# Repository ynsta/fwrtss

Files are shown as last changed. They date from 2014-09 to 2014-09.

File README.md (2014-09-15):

fwrtss
======

[FWRTSS](https://www.ynsta.org/fwrtss/doc/html/fwrtss.html) is an open source hardware and software project of a temperature controlled soldering station designed to be used with Weller RT soldering tips.

The majority of the software used to build and debug this project are also open source:

 - KiCad (5126) for PCB design with the [amazing new interactive router from CERN team](http://www.ohwr.org/projects/cern-kicad/wiki/WorkPackages).

 - ARM cross GCC (4.8.3) & binutils,

 - GDB cross, stlink,

 - dfu-util,

 - python, pyside, pyqtgraph,

 - scons, make

 - asciidoc,

 - emacs,

 - ...

The main goal of this project was to teach myself some new stuffs as it is my first real project with a stm32 MCU and also my first surface mount PCB project with 0.5mm pitch components.
Disclaimer

# Warning
 
**A SOLDERING STATION IS A DANGEROUS TOOL**

FWRTSS open source software and hardware are provided "as is" and any express or implied warranties, including, but not limited to, the implied warranties of merchantability and fitness for a particular purpose are disclaimed. in no event shall Stany MARCEL be liable for any direct, indirect, incidental, special, exemplary, or consequential damages (including, but not limited to, procurement of substitute goods or services; loss of use, data, or profits; or business interruption) however caused and on any theory of liability, whether in contract, strict liability, or tort (including negligence or otherwise) arising in any way out of the use of this tool (in whole or in part), even if advised of the possibility of such damage.

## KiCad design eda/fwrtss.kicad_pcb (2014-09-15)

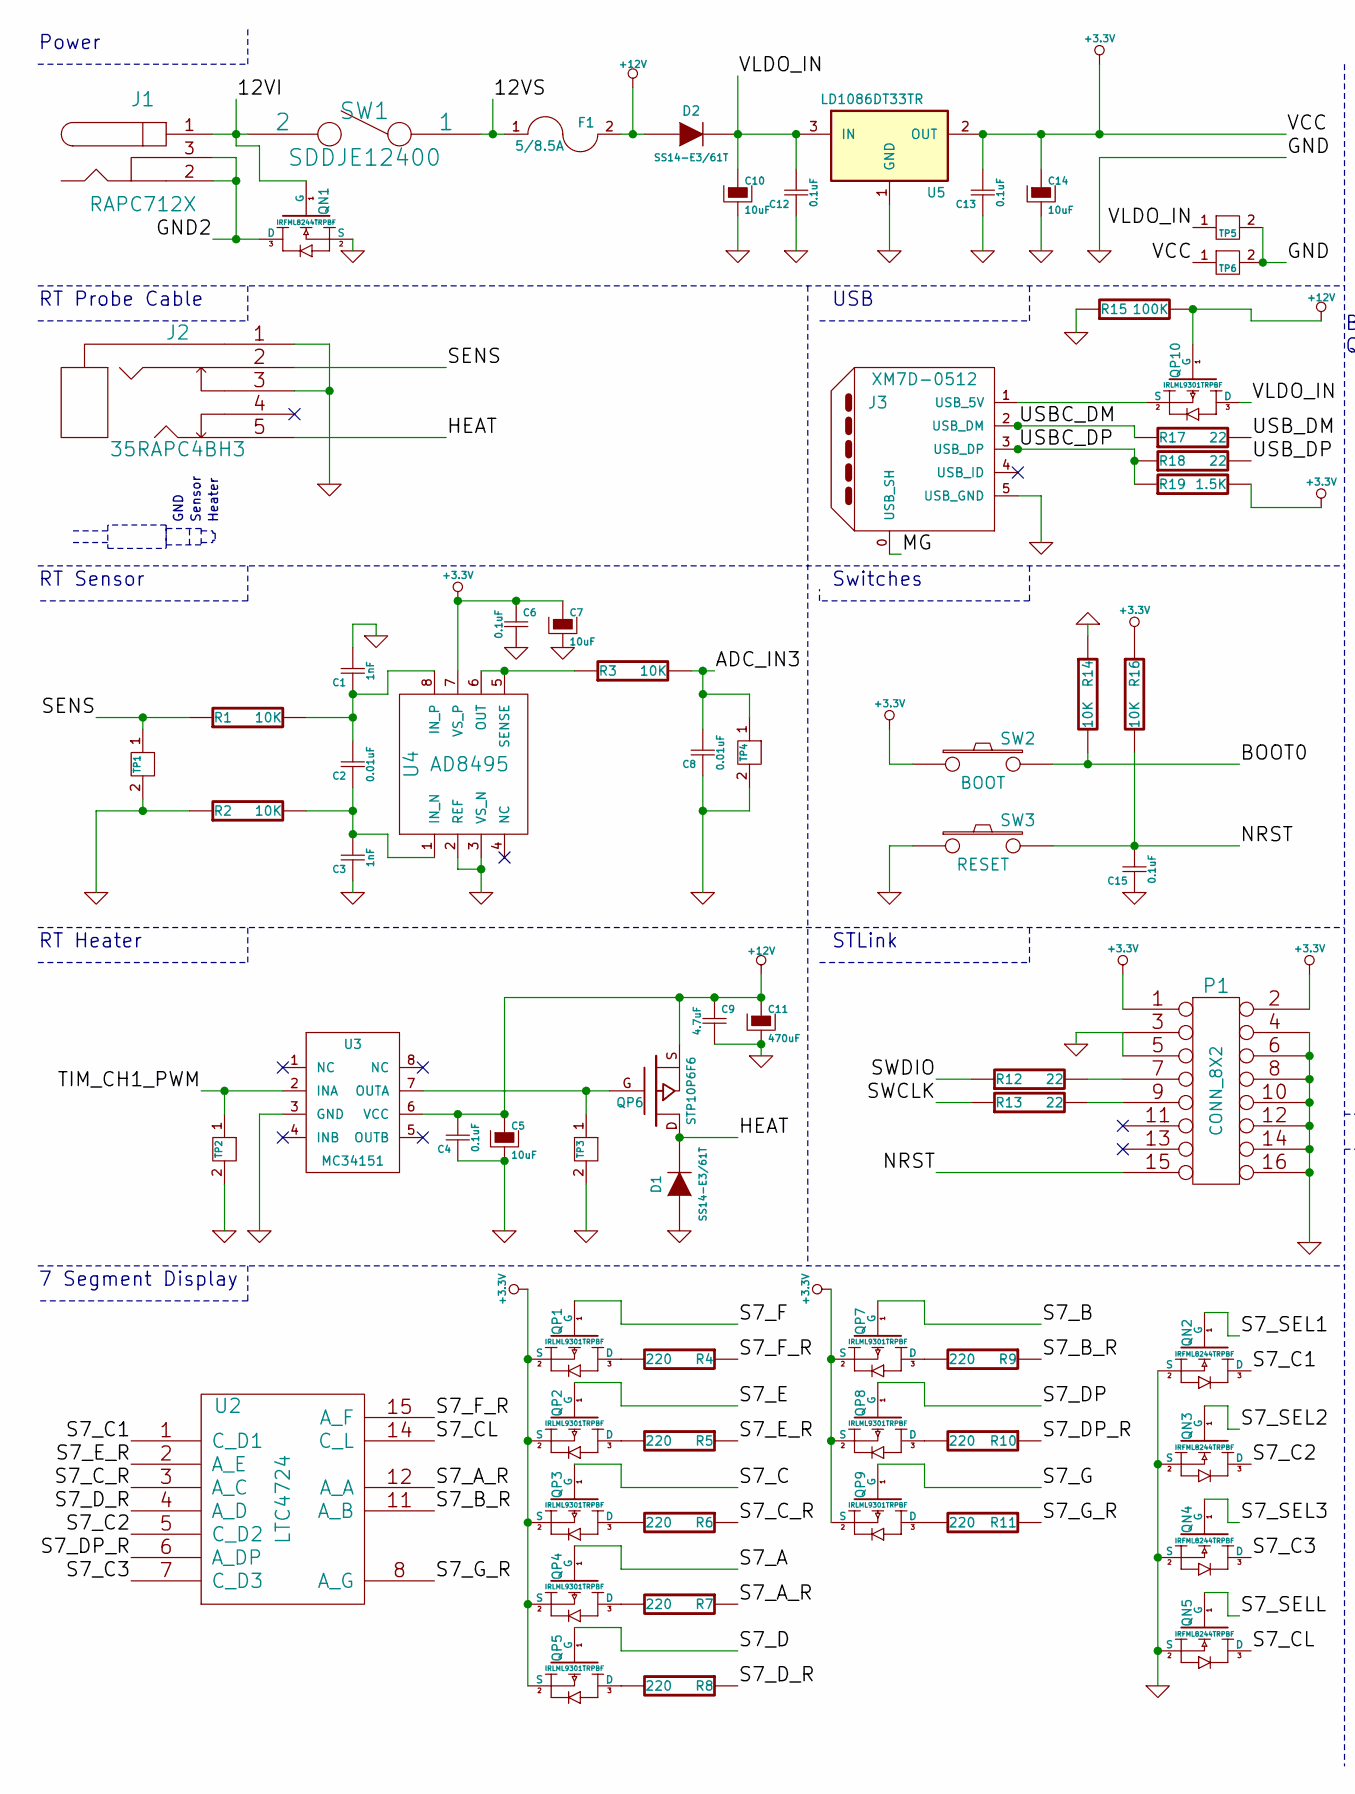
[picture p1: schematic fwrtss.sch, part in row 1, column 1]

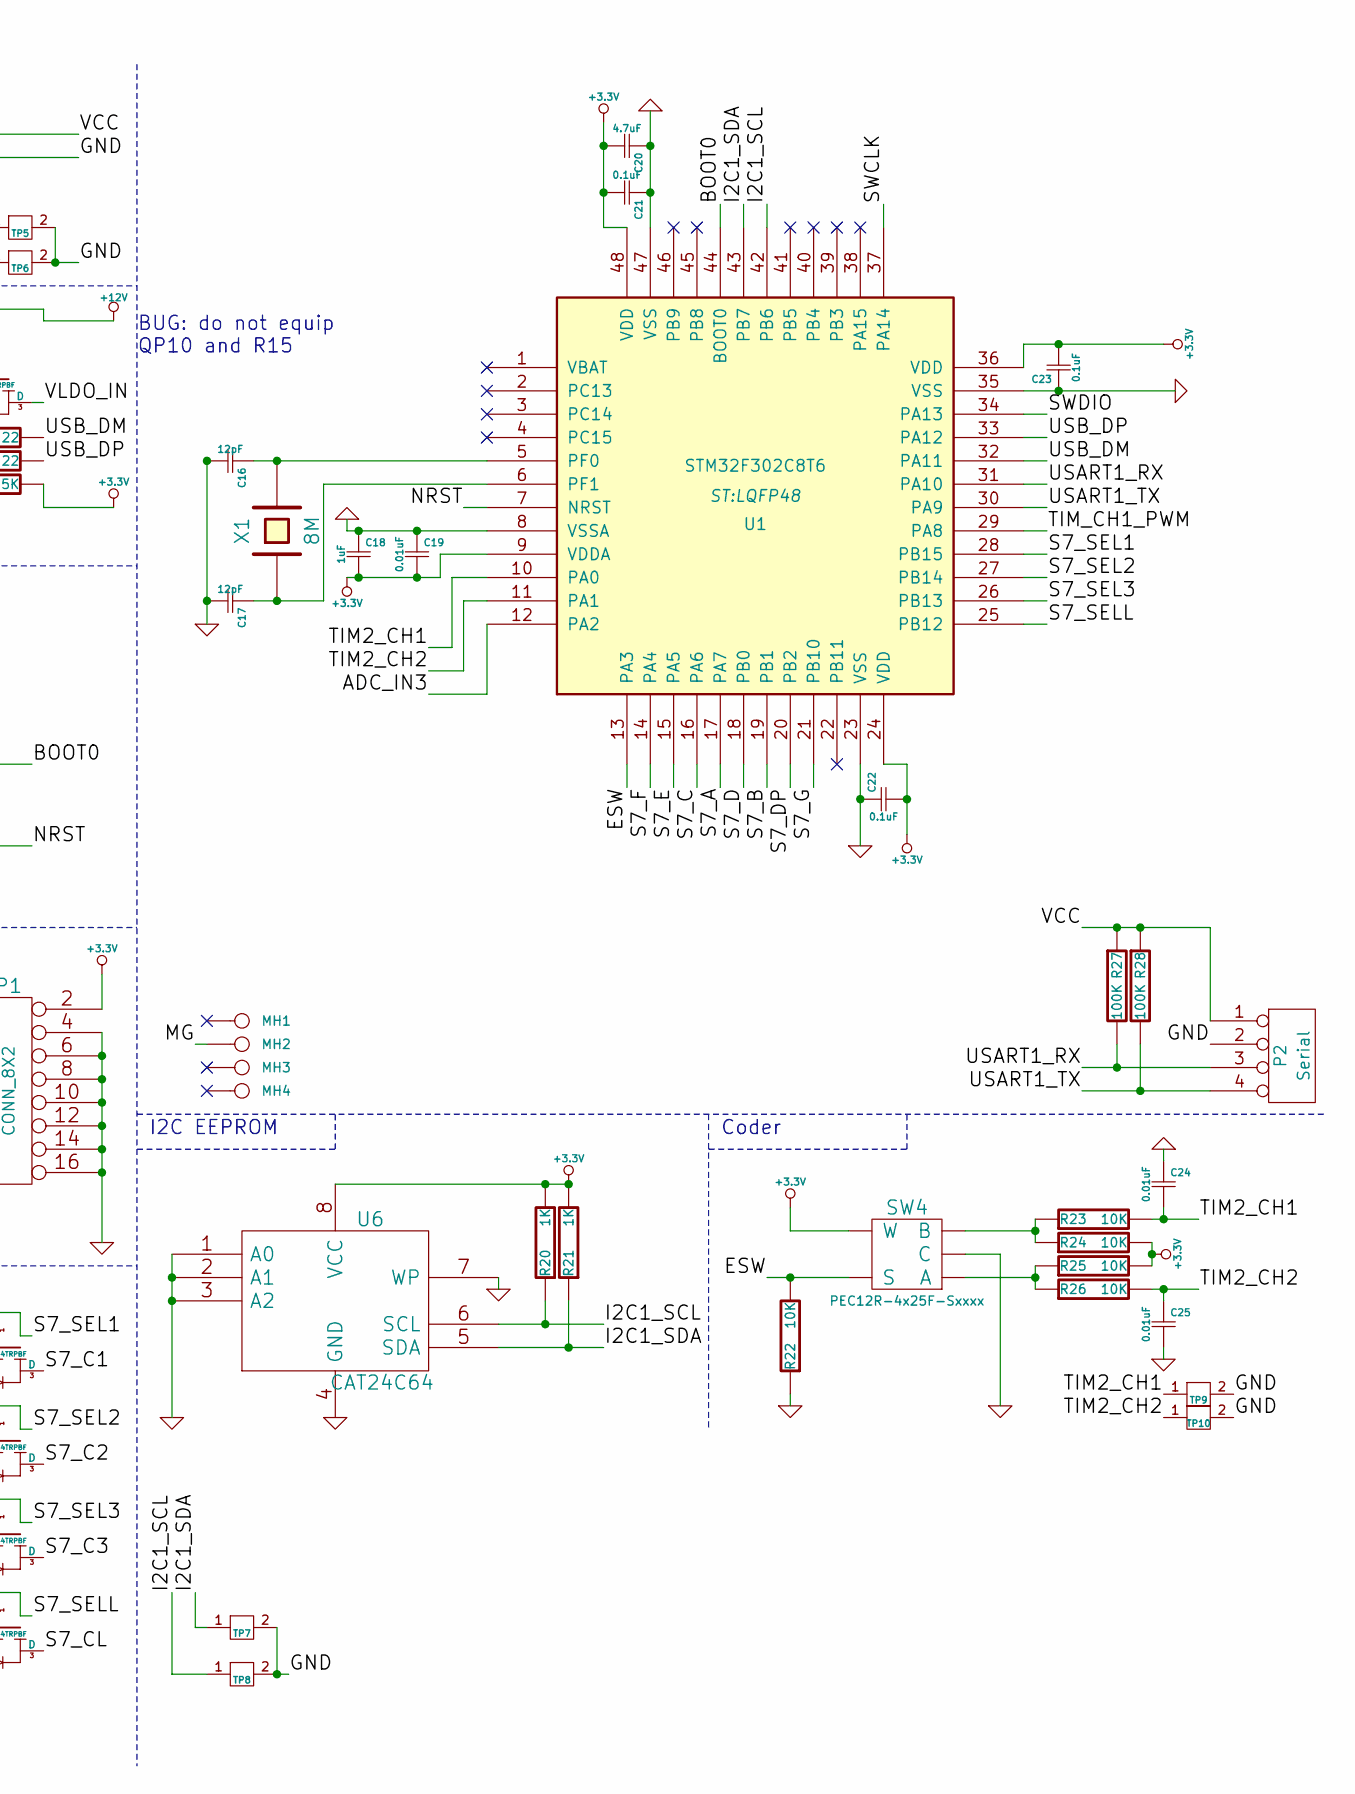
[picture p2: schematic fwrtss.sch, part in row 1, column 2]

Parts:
C1, C3: 1nF; 0805; mouser 81-GCM216R71H102KA7D
C2, C8, C19, C24, C25: 0.01uF; 0805; mouser 81-GRM40Y103Z50D
C4, C6, C12, C13, C15, C21, C22, C23: 0.1uF; 0805; mouser 81-GRM21R71C104MA01J
C5, C7, C10, C14: 10uF; Capacitor5x11RM2.5; mouser 667-EEU-EB1J100SH
C9, C20: 4.7uF; 0805; mouser 81-GRM21BR61E475KA12
C11: 470uF; Capacitor10x21RM5; mouser 647-UPW1E471MPD
C16, C17: 12pF; 0603; mouser 81-GQM1885C1H120JB01
C18: 1uF; 0805; mouser 81-GRM40X105K16L
D1, D2: SS14-E3/61T; DO214AC; mouser 625-SS14-E3
F1: 5/8.5A; Fuse_TE5_Littlefuse-395Series; mouser 650-RGEF500
J1: RAPC712X; RAPC722X; mouser 502-RAPC712X
J2: 35RAPC4BH3; mouser 502-35RAPC4BH3
J3: XM7D-0512; mouser 653-XM7D-0512
MH1, MH2, MH3, MH4: CONN_1; 1pin
P1: CONN_8X2; Pin_Header_Straight_2x08; mouser 649-67996-416HLF
P2: Serial; Pin_Header_Straight_1x04
QN1, QN2, QN3, QN4, QN5: IRFML8244TRPBF; sot23; mouser 942-IRFML8244TRPBF
QP1, QP2, QP3, QP4, QP5, QP7, QP8, QP9, QP10: IRLML9301TRPBF; sot23; mouser 942-IRLML9301TRPBF
QP6: STP10P6F6; TO-220_FET-GDS_Horizontal_LargePads; mouser 511-STP10P6F6
R1, R2, R3, R14, R16, R22, R23, R24, R25, R26: 10K; 0805; mouser 667-ERJ-6ENF1002V
R4, R5, R6, R7, R8, R9, R10, R11: 220; 0805; mouser 667-ERJ-6GEYJ221V
R12, R13, R17, R18: 22; 0805; mouser 667-ERJ-6GEYJ220V
R15, R27, R28: 100K; 0805; mouser 667-ERJ-6GEYJ104V
R19: 1.5K; 0805; mouser 667-ERJ-6GEYJ152V
R20, R21: 1K; 0805; mouser 667-ERJ-6GEYJ102V
SW1: SDDJE12400; mouser 688-SDDJE12400
SW2: BOOT; EVQ2; mouser 667-EVQ-21305R
SW3: RESET; EVQ2; mouser 667-EVQ-21305R
SW4: PEC12R-4x25F-Sxxxx; mouser 652-PEC12R-4225F-S24
TP1, TP2, TP3, TP4, TP5, TP6, TP7, TP8, TP9, TP10: TP2
U1: STM32F302C8T6; LQFP48; mouser 511-STM32F302C8T6
U2: LTC4724; LTC-4724; mouser 859-LTC-4724JR
U3: MC34151; SOIC-8_N; mouser 863-MC34151DR2G
U4: AD8495; MSOP-8; mouser 584-AD8495ARMZ
U5: LD1086DT33TR; DPAK2; mouser 511-LD1086DT33-TR
U6: CAT24C64; SOIC-8_N; mouser 698-CAT24C64WI-G
X1: 8M; X-TH-8.8-dia3.2; mouser 815-AB308-8.000

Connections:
+3.3V: C6.1, C7.1, C13.2, C14.1, C18.2, C19.2, C20.2, C21.2, C22.2, C23.2, P1.1, P1.2, P2.1, QP1.2 (S), QP2.2 (S), QP3.2 (S), QP4.2 (S), QP5.2 (S), QP7.2 (S), QP8.2 (S), QP9.2 (S), R16.1, R19.2, R20.2, R21.2, R24.2, R25.2, R27.1, R28.1, SW2.1, SW4.2 (W), TP6.1, U1.9 (VDDA), U1.24 (VDD), U1.36 (VDD), U1.48 (VDD), U4.7 (VS_P), U5.2 (OUT), U6.8 (VCC)
+12V: C4.2, C5.1, C9.1, C11.1, D2.1 (A), F1.2, QP6.S, QP10.1 (G), R15.2, U3.6 (VCC)
/12VI: J1.1, QN1.1 (G), SW1.2
/12VS: F1.1, SW1.1
/ADC_IN3: C8.2, R3.2, TP4.1, U1.12 (PA2)
/BOOT0: R14.2, SW2.2, U1.44 (BOOT0)
/ESW: R22.2, SW4.1 (S), U1.13 (PA3)
/GND2: J1.2, J1.3, QN1.3 (D)
/HEAT: D1.2 (K), J2.5, QP6.D
/I2C1_SCL: R20.1, TP8.1, U1.42 (PB6), U6.6 (SCL)
/I2C1_SDA: R21.1, TP7.1, U1.43 (PB7), U6.5 (SDA)
/MG: J3.0 (USB_SH), MH2.1
/NRST: C15.2, P1.15, R16.2, SW3.2, U1.7 (NRST)
/S7_A: QP4.1 (G), U1.17 (PA7)
/S7_A_R: R7.1, U2.12 (A_A)
/S7_B: QP7.1 (G), U1.19 (PB1)
/S7_B_R: R9.1, U2.11 (A_B)
/S7_C: QP3.1 (G), U1.16 (PA6)
/S7_C1: QN2.3 (D), U2.1 (C_D1)
/S7_C2: QN3.3 (D), U2.5 (C_D2)
/S7_C3: QN4.3 (D), U2.7 (C_D3)
/S7_CL: QN5.3 (D), U2.14 (C_L)
/S7_C_R: R6.1, U2.3 (A_C)
/S7_D: QP5.1 (G), U1.18 (PB0)
/S7_DP: QP8.1 (G), U1.20 (PB2)
/S7_DP_R: R10.1, U2.6 (A_DP)
/S7_D_R: R8.1, U2.4 (A_D)
/S7_E: QP2.1 (G), U1.15 (PA5)
/S7_E_R: R5.1, U2.2 (A_E)
/S7_F: QP1.1 (G), U1.14 (PA4)
/S7_F_R: R4.1, U2.15 (A_F)
/S7_G: QP9.1 (G), U1.21 (PB10)
/S7_G_R: R11.1, U2.8 (A_G)
/S7_SEL1: QN2.1 (G), U1.28 (PB15)
/S7_SEL2: QN3.1 (G), U1.27 (PB14)
/S7_SEL3: QN4.1 (G), U1.26 (PB13)
/S7_SELL: QN5.1 (G), U1.25 (PB12)
/SENS: J2.2, R1.1, TP1.1
/SWCLK: R13.1, U1.37 (PA14)
/SWDIO: R12.1, U1.34 (PA13)
/TIM2_CH1: C24.2, R23.2, TP9.1, U1.10 (PA0)
/TIM2_CH2: C25.1, R26.2, TP10.1, U1.11 (PA1)
/TIM_CH1_PWM: TP2.1, U1.29 (PA8), U3.2 (INA)
/USART1_RX: P2.3, R27.2, U1.31 (PA10)
/USART1_TX: P2.4, R28.2, U1.30 (PA9)
/USBC_DM: J3.2 (USB_DM), R17.1
/USBC_DP: J3.3 (USB_DP), R18.1, R19.1
/USB_DM: R17.2, U1.32 (PA11)
/USB_DP: R18.2, U1.33 (PA12)
/VLDO_IN: C10.1, C12.2, D2.2 (K), QP10.3 (D), TP5.1, U5.3 (IN)
GND: C1.2, C3.1, C4.1, C5.2, C6.2, C7.2, C8.1, C9.2, C10.2, C11.2, C12.1, C13.1, C14.2, C15.1, C16.2, C17.2, C18.1, C19.1, C20.1, C21.1, C22.1, C23.1, C24.1, C25.2, D1.1 (A), J2.1, J2.3, J3.5 (USB_GND), P1.3, P1.4, P1.5, P1.6, P1.8, P1.10, P1.12, P1.14, P1.16, P2.2, QN1.2 (S), QN2.2 (S), QN3.2 (S), QN4.2 (S), QN5.2 (S), R2.1, R14.1, R15.1, R22.1, SW3.1, SW4.4 (C), TP1.2, TP2.2, TP3.2, TP4.2, TP5.2, TP6.2, TP7.2, TP8.2, TP9.2, TP10.2, U1.8 (VSSA), U1.23 (VSS), U1.35 (VSS), U1.47 (VSS), U3.3 (GND), U4.2 (REF), U4.3 (VS_N), U5.1 (GND), U6.1 (A0), U6.2 (A1), U6.3 (A2), U6.4 (GND), U6.7 (WP)
unnamed: C1.1, C2.2, R1.2, U4.8 (IN_P)
unnamed: C2.1, C3.2, R2.2, U4.1 (IN_N)
unnamed: C16.1, U1.5 (PF0), X1.2
unnamed: C17.1, U1.6 (PF1), X1.1
unnamed: J3.1 (USB_5V), QP10.2 (S)
unnamed: P1.7, R12.2
unnamed: P1.9, R13.2
unnamed: QP1.3 (D), R4.2
unnamed: QP2.3 (D), R5.2
unnamed: QP3.3 (D), R6.2
unnamed: QP4.3 (D), R7.2
unnamed: QP5.3 (D), R8.2
unnamed: QP6.G, TP3.1, U3.7 (OUTA)
unnamed: QP7.3 (D), R9.2
unnamed: QP8.3 (D), R10.2
unnamed: QP9.3 (D), R11.2
unnamed: R3.1, U4.5 (SENSE), U4.6 (OUT)
unnamed: R23.1, R24.1, SW4.3 (B)
unnamed: R25.1, R26.1, SW4.5 (A)

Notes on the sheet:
Heater
Sensor
GND
7 Segment Display
RT Heater
RT Sensor
RT Probe Cable
Power
STLink
Coder
Switches
USB
I2C EEPROM
BUG: do not equip QP10 and R15

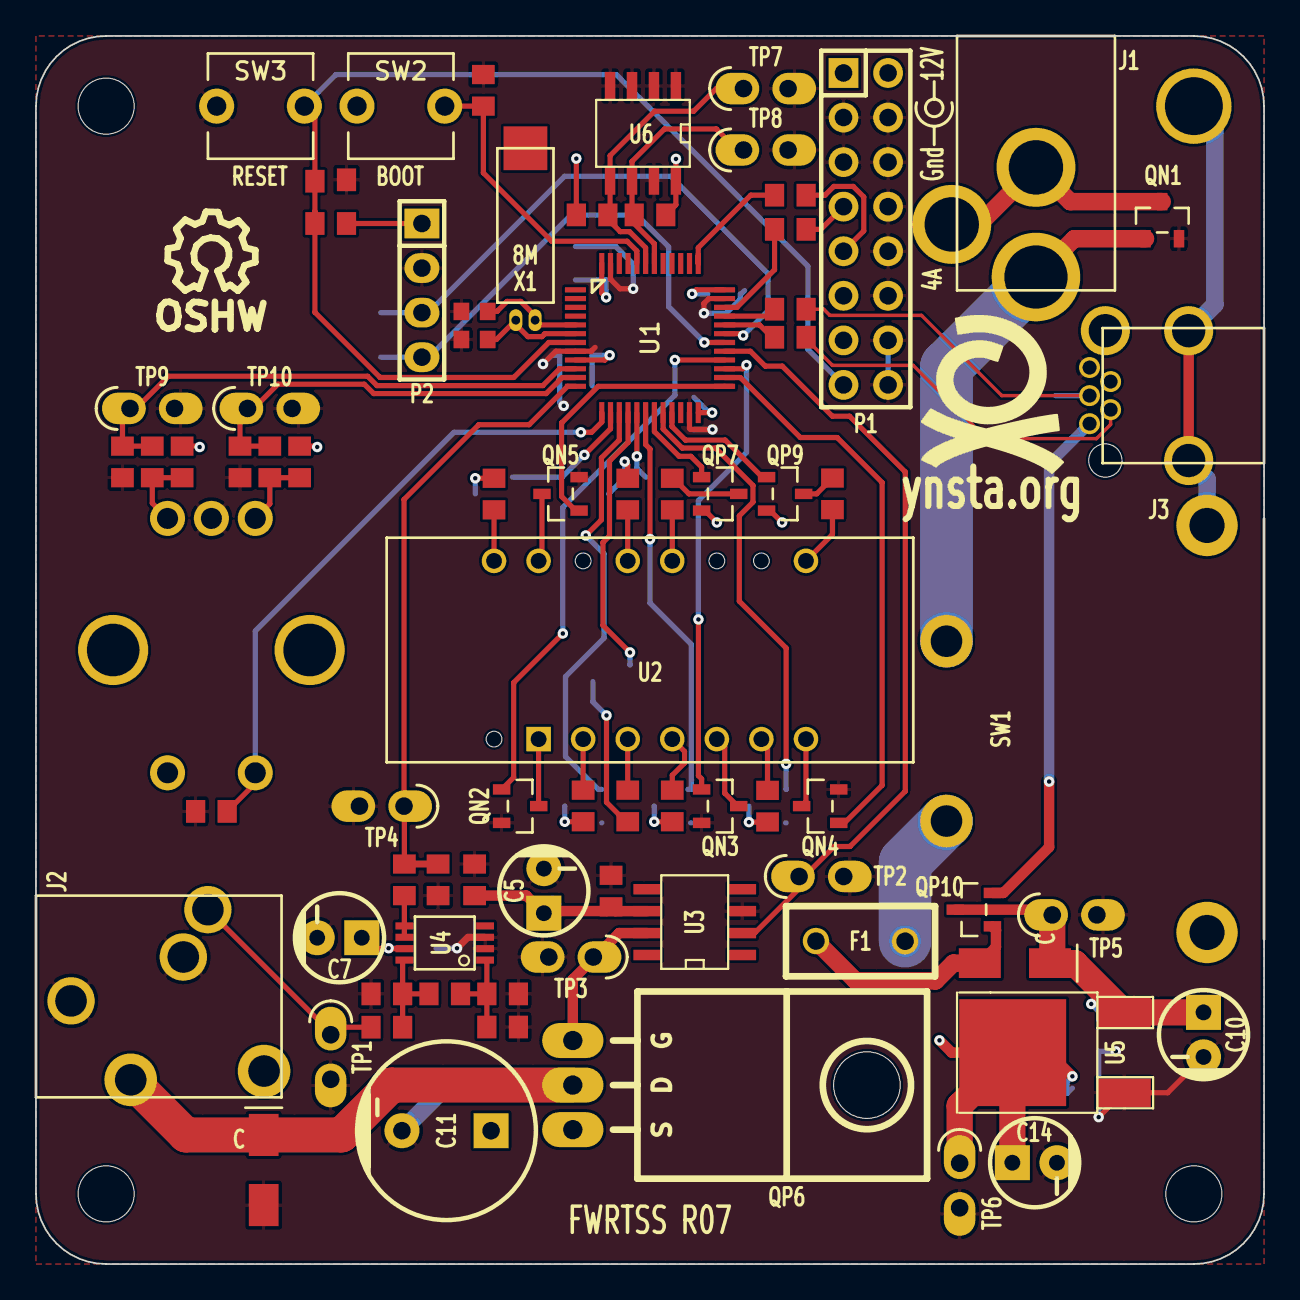
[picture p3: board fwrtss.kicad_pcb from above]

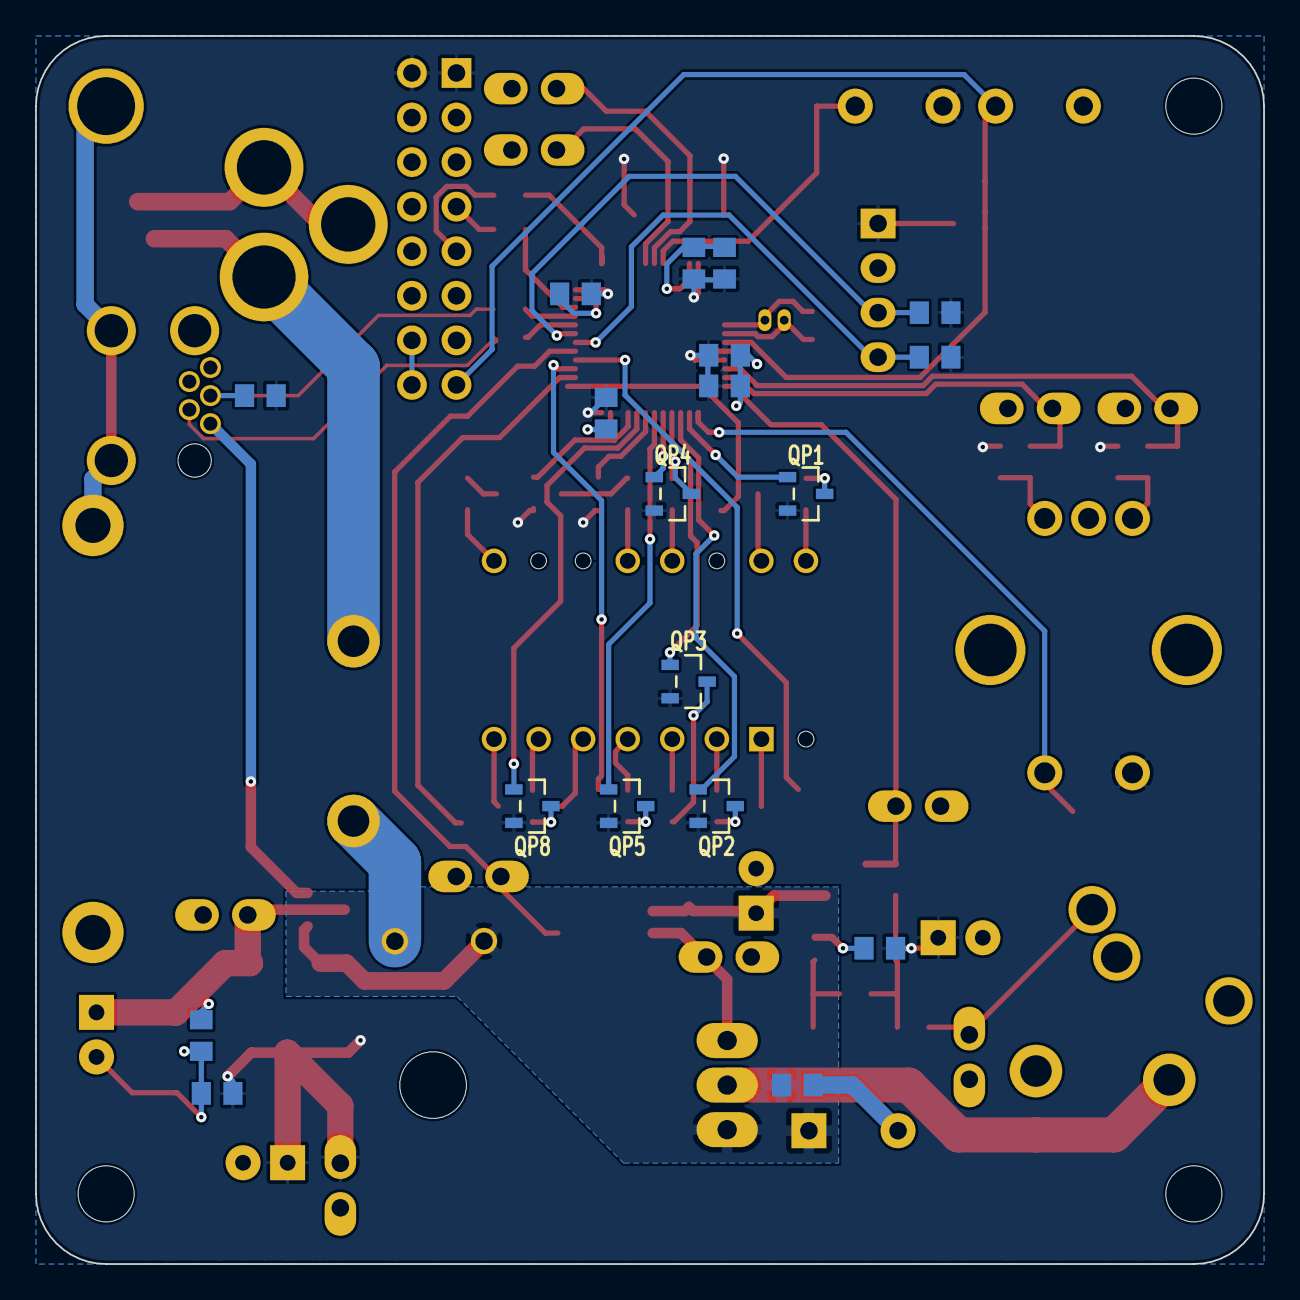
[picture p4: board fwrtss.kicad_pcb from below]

Board: 2 copper layers, 70.0 x 70.0 mm, 102 parts (19 on the bottom side), 70 nets.

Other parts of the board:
SYM: Symbol_OSHW-Logo_SilkScreen_07Jul2012; Symbol_OSHW-Logo_SilkScreen

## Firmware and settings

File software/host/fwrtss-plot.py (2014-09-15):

#!/usr/bin/env python
# -*- coding: utf-8 -*-

#
# Copyright (c) 2014, Stany MARCEL <stanypub@gmail.com>
# All rights reserved.
#
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


# SETUP:
#
# Instal pip with your distribution (apt-get install python-pip for example)
# package installer then run :
#
# sudo pip install PySide
# sudo pip install pyqtgraph
# sudo pip install pyserial
# sudo pip install crcmod

import serial
import struct
import crcmod
import ctypes
import numpy as np
import PySide
import pyqtgraph as pg
from pyqtgraph.Qt import QtGui, QtCore
import time

import os
from cStringIO import StringIO
from base64 import b64decode
from gzip import GzipFile
import tempfile

VERSION     = '0.3'
DESCRIPTION = 'FWRTSS plot (C)Stany MARCEL 2014 (https://www.ynsta.org)'

FWRTSS_MESSAGE_FORMAT = [
    ('id',        'B'),
    ('pmode',     'B'),
    ('count',     'H'),
    ('period_ms', 'I'),
    ('tempdc',    'f'),
    ('target',    'f'),
    ('pwm_dc',    'f'),
    ('offset',    'f'),
    ('cycle_ms',  'I'),
    ('crc',       'I'),
]

# Generated with gzip -c icon.sv | base64
ICON_DATA = '''
H4sICCC08FMAA2ljb24uc3ZnAO1X23LjxhF911cg2JfdMjGc+4Um5YdsOeUqP9lO5RkChhSyIMAA
oCj563MGxIUSuclWYjuXMlkqYbp7ZrpPd58G198878voyTdtUVebmBEaR77K6ryodpv4zz99m9g4
aru0ytOyrvwmrur4m/u79R+SJPpj49PO59Gp6B6j76pPbZYefPT+sesOq+XydDqRYhCSutktP0RJ
cn93t26fdndRFOHeql3l2SYeNhyOTdkb5tnSl37vq65dMsKW8WyezeZZuL148lm939dV2++s2ncX
xk2+nayDNyfRGzHn3JLyJecJLJL2perS5+T1Vvh4ayunlC6hmy2/zGrVAtAD/ibzUUDa+thkfot9
nlS+W3786eOkTCjJu/zimBHPV7e+ArlK9749pJlvl6O8338q8u4R+eW0Xz76YvfYzesi38TwmPeL
i2pgZ+1w0mrSUCItkVHjnHC9yejyKq+z4MMmfqlQNiTAcA+Dde63bTA83xVWsldAVRaVT5s/NWle
IOdno7PZa40wzgx7sKvt6sNoi/u7lxKXBmGS1WXdrN5t+8/XvagGJEX3smJfx/OeerttPUCgF7Ie
COzAXS6Olv/ebfTWbezWbZay6bb18nXYPXzLgFj/NCEdYM6fCn+aYX1IWz8cf0h3vndtEw++DYqH
usl9M6p0/3mlGrw/k8Fw9lgA4dRJT2/r28c0r0+bmL9V/lzXe4iJfavInjex5cRxI6y7UuImZYhi
TEj5VolqOwaiSI5V0aEZD89X249NEwzK9MUj4P7fmIL2sT7tmgDcNi0n5Iaj9vthvS26ZJ82u6JK
kKq5XC7kpd92NxXNuc1uaB7qrgtwXEF4KirAl0wNq6/gGizGHjb2CpbBArBq+bntIcHqczv36XOx
L372eXDwXJjrve/SPO3SudxGydiVa/Dp6oeP305dk2Wrv9TNp7ngg0H6UB/h9tTJgRyyFRhwn3b3
xR4VFMjzKzAeqn5SvDLuXg5+PvR8bOPPVHpznuTZvgiblj92RVl+Fy656O7h0KIr/UXLLwfvx668
CG69HEPvV7s3IJbpgy838feh1iL2FuJdUx8P+zr3QzXGM6CvqrNr0qoN0W/i/rHEsH2fcGuJWiTc
8Q8T6j6bWHNgpi2inDgpLC4YsO2a+pNfvcts+A7Lc72tGBHMassk6O/80aPBdMDEX8HjcLegzE3C
sW6ZJThH8EkxjZwrDcqUW0eYUkJPQpQnYiQgJzpbNkEqiJLG2pkvD2n3OMU/smPINsj1UDRpGb9B
Z+JnwnpwVhVebSZcaP95g8u0DtyMNK7avx3Txl9K/1oX1Qq5rfJRiprzTYlG6lbyCsZRkKcgzKZJ
X3ovXoEbAuPOqvgqusCYQjEiuVX6hho4CU6JE0Lza7V/PqCexhEvrg0a/1SXx6634IQ7J6U0N8ww
oI6gSimQJ0PdDUdBdj1Bb+IEebfSqVv+djRME8WFMtLO/gSKiSBDmMaxhZCYSMZoHWVRwhixjku2
UERp5XSUcIXzUYqLBGbWWBclIkBApYSIE8Mg0QSICAOBJEqgjCKcQ5nALtEXv5ER04SiASxEhnDF
cBLDg0DbGcKMMZHQxDEj3YLjEK14BAQMpUIsmCNSGRVZQqlVLKydsVrBF+AI2UKiqDm18BcTT2gt
FooSrqlFCGEX5XwhCGMs2MAVa6Uxi4AwZ32QnDtpFwxNpObcXpAF2LIpnt8jdGUY5YYvKL54l7Ra
WGOsWrgAqA5PmoWIqPvwmW76V/vFESOEkprrt33zcOy6q67pG+WX6JpzxVCHmrBKLSSl4a2CSlQM
QECuEbTgCwAtrFWRlIQ5LpBp5ElbVAM3xDmreUi17JMicQRKoN9kUATiWnLVtMKYuRfmV5G6AgZd
3SR4KXlKu2PjL18+5xc7zIZAX+isrM3+rzLjJEGLaonMSHSb1GbIDKDkUsmQiYCusDxK0BfoLYXu
RatwJhlk1/lJ0IwMPCeGnkaD3pLdzFHCf+Usfck0us6b9Ipp9t80gZIbQ+L3GfT7DPrnM8giHLxO
TjNICHQjD4+OU6kZItJUEaEAyT+eQl/WJ4HH8TtSy//I4EFOMGIBntPEaM7FNHisYKqfGDRkLZII
WWgaCMqC0TjH6OmnSc9szGmHhDLkDYkLuySTtyS3WY3+JrPnfyAfGDeYNrx/D6ACZT1PG6lswJGF
ljdGYNoAWy1CW/Ke0zjGyFVKQjdSbc15sFBmtLsl+8ywuWDRXyYx6+Xu/m4dfi7f3/0dHrQw1coV
AAA=
'''


class FWRTSSMessage:
    def __init__(self,
                 bigendian = False):
        self._fields_desc = FWRTSS_MESSAGE_FORMAT
        self._format = ''.join([fmt for (_, fmt) in self._fields_desc])
        self._fields = [f for (f, _) in self._fields_desc]
        num = 0
        self._index = {}
        for field in self._fields:
            self._index[field] = num
            num = num + 1
        self._data = self._nulldata()
        self._is_big = bigendian

    def _get_format(self):
        return self._format

    def _get_fields(self):
        return self._fields

    def _encode(self, datas):
        return struct.pack(self._format, *datas)

    def _decode(self, buf):
        return list(struct.unpack(self._format, buf))

    def _nullbuff(self):
        return self.getsize() * '\x00'

    def _nulldata(self):
        return self._decode(self._nullbuff())

    def _getidx(self, field):
        assert field in self._index.keys(), \
            'ERROR: unknown field %s not in (%s)' % (
                field, ','.join([str(_x) for _x in self._index.keys()]))
        return self._index[field]

    def setfield(self, field, val):
        idx = self._getidx(field)
        self._data[idx] = val

    def setfields(self, field_dict):
        for field, val in field_dict.items():
            idx = self._getidx(field)
            self._data[idx] = val

    def getfield(self, field):
        idx = self._getidx(field)
        return self._data[idx]

    def getfields(self):
        out = dict()
        for key, index in self._index.items():
            out[key] = self._data[index]
        return out

    def setbuf(self, buf):
        self._data = self._decode(buf)

    def getbuf(self):
        return self._encode(self._data)

    def getdata(self):
        return self._data

    def getfieldoffset(self, field):
        idx = self._getidx(field)
        if self._is_big:
            fmt = '>'
        else:
            fmt = '<'
        for i in range(0, idx):
            fmt = fmt + self._fields_desc[i][1]
        return struct.calcsize(fmt)

    def getsize(self):
        return struct.calcsize(self._format)


class FWRTSSError(Exception):
    def __init__(self, value):
        self.value = value
    def __str__(self):
        if type(self.value) == str:
            return self.value
        else:
            return repr(self.value)




class FWRTSSReader:

    def __init__(self, port):

        try:
            import termios
            fd = open(port)
            tmp = termios.tcgetattr(fd.fileno())
            termios.tcsetattr(fd.fileno(), termios.TCSADRAIN, tmp)
            fd.close()
        except (ImportError, IOError, termios.error):
            pass

        self._msg = FWRTSSMessage()

        self._ser = None

        self._buf = []

        self._crc = crcmod.mkCrcFun(0x104c11db7, initCrc=0xFFFFFFFF, xorOut=0, rev=False)

        try:
            self._ser = serial.Serial(port, 115200)
            self._ser.flush()
            self._ser.flushInput()
            self._ser.flushOutput()
            self._ser.timeout = 0.2
        except serial.serialutil.SerialException, e:
            raise FWRTSSError(str(e))

    def __del__(self):
        if self._ser:
            self._ser.close()


    def read(self):

        def _swap(buf):
            return ''.join([buf[i+3]+buf[i+2]+buf[i+1]+buf[i] for i in range(0, len(buf), 4)])

        def _checkcrc32(buf, crc):
            val = self._crc(_swap(buf[:-4]))
            return ctypes.c_uint32(val).value == ctypes.c_uint32(crc).value

        size = self._msg.getsize()

        try:
            self._buf += self._ser.read()
        except serial.serialutil.SerialException:
            time.sleep(0.1)

        if not self._buf or len(self._buf) < size:
            return None

        sbuf = ''.join(self._buf[0:size])
        self._msg.setbuf(sbuf)

        msg_id  = self._msg.getfield('id')
        msg_crc = self._msg.getfield('crc')

        while msg_id != 0xAA or not _checkcrc32(self._buf[0:size], msg_crc):
            if len(self._buf) <= size:
                return None
            self._buf = self._buf[1:]
            sbuf = ''.join(self._buf[0:size])
            self._msg.setbuf(sbuf)
            msg_id  = self._msg.getfield('id')
            msg_crc = self._msg.getfield('crc')

        self._buf = self._buf[size:]

        fields = self._msg.getfields()

        return fields



class EbdData:

    def __init__(self, data):
        fd, fname = tempfile.mkstemp()
        gzd = GzipFile(mode='r', fileobj=StringIO(b64decode(data)))
        os.write(fd, gzd.read())
        os.close(fd)
        gzd.close()
        self.name = fname

    def __del__(self):
        os.unlink(self.name)

    def __str__(self):
        return self.name


if __name__ == '__main__':

    import argparse
    import sys
    parser = argparse.ArgumentParser(description=DESCRIPTION, version=VERSION)
    parser.add_argument('device', nargs=1,
                        type=argparse.FileType('rw'),
                        help='fwrtss serial device')
    parser.add_argument('-t',
                        type=int,
                        default=5,
                        dest='sec',
                        help='display depth in seconds')

    args = parser.parse_args()

    if args.sec <= 0:
        args.sec = 1

    device = args.device[0].name
    args.device[0].close()

    try:
        rd = FWRTSSReader(device)
    except FWRTSSError as e:
        sys.sterr.write("Serial error\n\r")
        sys.exit(1)

    icon = EbdData(ICON_DATA)

    app = QtGui.QApplication([])
    view = pg.GraphicsWindow(title=('fwrtss (%s)' % device))
    l = pg.GraphicsLayout(border=(100,100,100))
    view.setCentralItem(l)
    view.show()
    view.resize(800,800)
    view.setWindowIcon(QtGui.QIcon(str(icon)))

    datas = {}
    curve = {}
    label = {}
    texts = {}
    cp    = {}
    arrow = {}

    colors = {
        'tempdc' : (255,0,0),
        'target' : (0,255,0),
        'pwm_dc' : (0,255,255),
        'offset' : (20,100,255),
    }

    CURVE_A = 0.65

    l.addLabel('<b>FWRTSS PLOT ' + VERSION + ' by Stany MARCEL (%s)</b>' % device,
               col=0, row=0, colspan=2)

    l.nextRow()

    # == MODE LABEL ==
    label['pmode'] = l.addLabel('fwrtss mode : Unknown', angle=-90, col=0, row=1, rowspan=3)
    texts['pmode'] = {
        0 : 'fwrtss mode : Settings',
        1 : 'fwrtss mode : Run',
        2 : 'fwrtss mode : Backup',
        3 : 'fwrtss mode : Calibration',
    }

    msg = rd.read()
    while not msg:
        msg = rd.read()

    period = msg['period_ms'] / 1000.0
    x = np.arange(-(args.sec) + period, period, period)

    # == PLOT TEMPERATURES ==
    p1 = l.addPlot(name='Plot1', title='Temperatures', col=1, row=1)
    p1.addLegend()
    p1.setLabel('left', 'temperature', units='oC')
    p1.setLabel('bottom', 'time', units='s')
    p1.setRange(xRange=(-(args.sec),0), yRange=(0,500))
    p1.showGrid(x=False, y=True, alpha=0.5)
    datas['tempdc'] = [0] * int(args.sec / period)
    curve['tempdc'] = p1.plot(x=x, y=datas['tempdc'], pen=colors['tempdc'], name='curent')
    curve['tempdc'].setOpacity(CURVE_A)
    datas['target'] = [0] * int(args.sec / period)
    curve['target'] = p1.plot(x=x, y=datas['target'], pen=colors['target'], name='target')
    curve['target'].setOpacity(CURVE_A)
    cp['tempdc'] = pg.CurvePoint(curve['tempdc'])
    p1.addItem(cp['tempdc'])
    label['tempdc'] = pg.TextItem(text="", anchor=(1, 0.25), color=colors['tempdc'], angle=90)
    label['tempdc'].setParentItem(cp['tempdc'])

    cp['target'] = pg.CurvePoint(curve['target'])
    p1.addItem(cp['target'])
    label['target'] = pg.TextItem(text="", anchor=(1, -0.25), color=colors['target'], angle=90)
    label['target'].setParentItem(cp['target'])

    l.nextRow()

    # == PLOT DUTY CYCLE ==
    p2 = l.addPlot(name='Plot2', title='Duty cycle', col=1, row=2)
    p2.setXLink('Plot1')
    p2.setLabel('left', 'DC', units='%')
    p2.setLabel('bottom', 'time', units='s')
    p2.setRange(yRange=(0,100))
    p2.showGrid(x=False, y=True, alpha=0.5)

    datas['pwm_dc'] = [0] * int(args.sec / period)
    curve['pwm_dc'] = p2.plot(x=x, y=datas['pwm_dc'], pen=colors['pwm_dc'])
    curve['pwm_dc'].setOpacity(CURVE_A)

    cp['pwm_dc'] = pg.CurvePoint(curve['pwm_dc'])
    p2.addItem(cp['pwm_dc'])
    label['pwm_dc'] = pg.TextItem(text="", anchor=(0.9, 1), color=colors['pwm_dc'])
    label['pwm_dc'].setParentItem(cp['pwm_dc'])

    l.nextRow()

    # == PLOT TEMPERATURE OFFSET ==
    p3 = l.addPlot(name='Plot3', title='Temperature offset', col=1, row=3)
    p3.setXLink('Plot1')
    p3.setLabel('left', 'temperature', units='oC')
    p3.setLabel('bottom', 'time', units='s')
    p3.setRange(xRange=(-(args.sec),0), yRange=(-50,50))
    p3.showGrid(x=False, y=True, alpha=0.5)
    datas['offset'] = [0] * int(args.sec / period)
    curve['offset'] = p3.plot(x=x, y=datas['offset'], pen=colors['offset'], name='offset')
    curve['offset'].setOpacity(CURVE_A)

    cp['offset'] = pg.CurvePoint(curve['offset'])
    p3.addItem(cp['offset'])
    label['offset'] = pg.TextItem(text="", anchor=(0.9, 1), color=colors['offset'])
    label['offset'].setParentItem(cp['offset'])

    # == LAYOUT STRETCH ==
    l.layout.setRowStretchFactor(0, 0)
    l.layout.setRowStretchFactor(1, 6)
    l.layout.setRowStretchFactor(2, 4)
    l.layout.setRowStretchFactor(3, 1)

    # == UPDATE FUNC ==
    def update_curves():
        global datas, curve

        msg = rd.read()
        if not msg:
            return

        for k in datas.keys():
            datas[k] = datas[k][1:] + [ msg[k] ]
            curve[k].setData(x=x, y=datas[k])

        for k in cp.keys():
            cp[k].setPos(len(x))

        for k in label.keys():
            val = msg[k]
            if k in texts and val in texts[k]:
                label[k].setText('<b>' + texts[k][val] + '</b>')
            else:
                if type(val) == float:
                    label[k].setText(text='%.3f' % val, color=colors[k])
                else:
                    label[k].setText(text=str(val), color=colors[k])

        app.processEvents()

    timer = QtCore.QTimer()
    timer.timeout.connect(update_curves)
    timer.start(0)

    QtGui.QApplication.instance().exec_()

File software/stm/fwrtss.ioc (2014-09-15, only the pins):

Mcu.UserName=STM32F302C8Tx
PA0.GPIO_Label=ENC_CH1
PA0.Signal=S_TIM2_CH1_ETR
PA1.GPIO_Label=ENC_CH2
PA1.Signal=S_TIM2_CH2
PA10.Signal=USART1_RX
PA11.Signal=USB_DM
PA12.Signal=USB_DP
PA13.Signal=SYS_JTMS-SWDIO
PA14.Signal=SYS_JTCK-SWCLK
PA15.Signal=GPIO_Analog
PA2.GPIO_Label=SENS_IN
PA2.Signal=ADC1_IN3
PA3.Signal=S_TIM15_CH2
PA4.GPIO_Label=S7_F
PA4.Signal=GPIO_Output
PA5.GPIO_Label=S7_E
PA5.Signal=GPIO_Output
PA6.GPIO_Label=S7_C
PA6.Signal=GPIO_Output
PA7.GPIO_Label=S7_A
PA7.Signal=GPIO_Output
PA8.GPIO_Label=PWM_OUT
PA8.Signal=S_TIM1_CH1
PA9.Signal=USART1_TX
PB0.GPIO_Label=S7_D
PB0.Signal=GPIO_Output
PB1.GPIO_Label=S7_B
PB1.Signal=GPIO_Output
PB10.GPIO_Label=S7_G
PB10.Signal=GPIO_Output
PB11.Signal=GPIO_Analog
PB12.GPIO_Label=S7_SELL
PB12.Signal=GPIO_Output
PB13.GPIO_Label=S7_SEL3
PB13.Signal=GPIO_Output
PB14.GPIO_Label=S7_SEL2
PB14.Signal=GPIO_Output
PB15.GPIO_Label=S7_SEL1
PB15.Signal=GPIO_Output
PB2.GPIO_Label=S7_DP
PB2.Signal=GPIO_Output
PB3.Signal=GPIO_Analog
PB4.Signal=GPIO_Analog
PB5.Signal=GPIO_Analog
PB6.Signal=I2C1_SCL
PB7.Signal=I2C1_SDA
PB8.Signal=GPIO_Analog
PB9.Signal=GPIO_Analog
PC13.Signal=GPIO_Analog
PF0-OSC_IN.Signal=RCC_OSC_IN
PF1-OSC_OUT.Signal=RCC_OSC_OUT

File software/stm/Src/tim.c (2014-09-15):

/**
  ******************************************************************************
  * File Name          : TIM.c
  * Date               : 23/08/2014 13:36:00
  * Description        : This file provides code for the configuration
  *                      of the TIM instances.
  ******************************************************************************
  *
  * COPYRIGHT(c) 2014 STMicroelectronics
  *
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
  ******************************************************************************
  */

/* Includes ------------------------------------------------------------------*/
#include "tim.h"

#include "gpio.h"

TIM_HandleTypeDef htim1;
TIM_HandleTypeDef htim2;
TIM_HandleTypeDef htim6;
TIM_HandleTypeDef htim15;

/* TIM1 init function */
void MX_TIM1_Init(void)
{

  TIM_OC_InitTypeDef sConfigOC;
  TIM_BreakDeadTimeConfigTypeDef sBreakDeadTimeConfig;
  TIM_MasterConfigTypeDef sMasterConfig;

  htim1.Instance = TIM1;
  htim1.Init.Prescaler = 0;
  htim1.Init.CounterMode = TIM_COUNTERMODE_UP;
  htim1.Init.Period = 1000;
  htim1.Init.ClockDivision = TIM_CLOCKDIVISION_DIV1;
  htim1.Init.RepetitionCounter = 0;
  HAL_TIM_PWM_Init(&htim1);

  sConfigOC.OCMode = TIM_OCMODE_PWM1;
  sConfigOC.Pulse = 0;
  sConfigOC.OCPolarity = TIM_OCPOLARITY_HIGH;
  sConfigOC.OCFastMode = TIM_OCFAST_ENABLE;
  sConfigOC.OCIdleState = TIM_OCIDLESTATE_RESET;
  HAL_TIM_PWM_ConfigChannel(&htim1, &sConfigOC, TIM_CHANNEL_1);

  sBreakDeadTimeConfig.OffStateRunMode = TIM_OSSR_DISABLE;
  sBreakDeadTimeConfig.OffStateIDLEMode = TIM_OSSI_DISABLE;
  sBreakDeadTimeConfig.LockLevel = TIM_LOCKLEVEL_OFF;
  sBreakDeadTimeConfig.BreakState = TIM_BREAK_DISABLE;
  sBreakDeadTimeConfig.BreakPolarity = TIM_BREAKPOLARITY_HIGH;
  sBreakDeadTimeConfig.BreakFilter = 0;
  sBreakDeadTimeConfig.Break2State = TIM_BREAK2_DISABLE;
  sBreakDeadTimeConfig.Break2Polarity = TIM_BREAK2POLARITY_HIGH;
  sBreakDeadTimeConfig.Break2Filter = 0;
  sBreakDeadTimeConfig.AutomaticOutput = TIM_AUTOMATICOUTPUT_DISABLE;
  HAL_TIMEx_ConfigBreakDeadTime(&htim1, &sBreakDeadTimeConfig);

  sMasterConfig.MasterOutputTrigger = TIM_TRGO_RESET;
  sMasterConfig.MasterOutputTrigger2 = TIM_TRGO2_RESET;
  sMasterConfig.MasterSlaveMode = TIM_MASTERSLAVEMODE_DISABLE;
  HAL_TIMEx_MasterConfigSynchronization(&htim1, &sMasterConfig);

}
/* TIM2 init function */
void MX_TIM2_Init(void)
{

  TIM_Encoder_InitTypeDef sConfig;
  TIM_MasterConfigTypeDef sMasterConfig;

  htim2.Instance = TIM2;
  htim2.Init.Prescaler = 0;
  htim2.Init.CounterMode = TIM_COUNTERMODE_UP;
  htim2.Init.Period = 0xFFFFFFFF;
  htim2.Init.ClockDivision = TIM_CLOCKDIVISION_DIV1;
  sConfig.EncoderMode = TIM_ENCODERMODE_TI1;
  sConfig.IC1Polarity = TIM_ICPOLARITY_RISING;
  sConfig.IC1Selection = TIM_ICSELECTION_DIRECTTI;
  sConfig.IC1Prescaler = TIM_ICPSC_DIV1;
  sConfig.IC1Filter = 15;
  sConfig.IC2Polarity = TIM_ICPOLARITY_RISING;
  sConfig.IC2Selection = TIM_ICSELECTION_DIRECTTI;
  sConfig.IC2Prescaler = TIM_ICPSC_DIV1;
  sConfig.IC2Filter = 15;
  HAL_TIM_Encoder_Init(&htim2, &sConfig);

  sMasterConfig.MasterOutputTrigger = TIM_TRGO_RESET;
  sMasterConfig.MasterSlaveMode = TIM_MASTERSLAVEMODE_DISABLE;
  HAL_TIMEx_MasterConfigSynchronization(&htim2, &sMasterConfig);

}
/* TIM6 init function */
void MX_TIM6_Init(void)
{

  TIM_MasterConfigTypeDef sMasterConfig;

  htim6.Instance = TIM6;
  htim6.Init.Prescaler = 7200;
  htim6.Init.CounterMode = TIM_COUNTERMODE_UP;
  htim6.Init.Period = 49; /* 5 ms by digit */
  HAL_TIM_Base_Init(&htim6);

  sMasterConfig.MasterOutputTrigger = TIM_TRGO_RESET;
  sMasterConfig.MasterSlaveMode = TIM_MASTERSLAVEMODE_DISABLE;
  HAL_TIMEx_MasterConfigSynchronization(&htim6, &sMasterConfig);

}

/* TIM15 init function */
void MX_TIM15_Init(void)
{

  TIM_IC_InitTypeDef sConfigIC;
  TIM_MasterConfigTypeDef sMasterConfig;

  htim15.Instance = TIM15;
  htim15.Init.Prescaler = 18000;
  htim15.Init.CounterMode = TIM_COUNTERMODE_UP;
  htim15.Init.Period = 0xFFFF;
  htim15.Init.ClockDivision = TIM_CLOCKDIVISION_DIV4;
  htim15.Init.RepetitionCounter = 0;
  HAL_TIM_IC_Init(&htim15);

  sConfigIC.ICPolarity = TIM_INPUTCHANNELPOLARITY_BOTHEDGE;
  sConfigIC.ICSelection = TIM_ICSELECTION_DIRECTTI;
  sConfigIC.ICPrescaler = TIM_ICPSC_DIV1;
  sConfigIC.ICFilter = 10;
  HAL_TIM_IC_ConfigChannel(&htim15, &sConfigIC, TIM_CHANNEL_2);

  sMasterConfig.MasterOutputTrigger = TIM_TRGO_RESET;
  sMasterConfig.MasterSlaveMode = TIM_MASTERSLAVEMODE_DISABLE;
  HAL_TIMEx_MasterConfigSynchronization(&htim15, &sMasterConfig);

}

void HAL_TIM_PWM_MspInit(TIM_HandleTypeDef* htim_pwm)
{

  GPIO_InitTypeDef GPIO_InitStruct;
  if(htim_pwm->Instance==TIM1)
  {
    /* Peripheral clock enable */
    __TIM1_CLK_ENABLE();

    /**TIM1 GPIO Configuration
    PA8     ------> TIM1_CH1
    */
    GPIO_InitStruct.Pin = GPIO_PIN_8;
    GPIO_InitStruct.Mode = GPIO_MODE_AF_PP;
    GPIO_InitStruct.Pull = GPIO_NOPULL;
    GPIO_InitStruct.Speed = GPIO_SPEED_HIGH;
    GPIO_InitStruct.Alternate = GPIO_AF6_TIM1;
    HAL_GPIO_Init(GPIOA, &GPIO_InitStruct);

    /* Peripheral interrupt init*/
    /* Sets the priority grouping field */
    HAL_NVIC_SetPriorityGrouping(NVIC_PRIORITYGROUP_3);
    HAL_NVIC_SetPriority(TIM1_BRK_TIM15_IRQn, 1, 0);
    HAL_NVIC_EnableIRQ(TIM1_BRK_TIM15_IRQn);
  }
}

void HAL_TIM_Encoder_MspInit(TIM_HandleTypeDef* htim_encoder)
{

  GPIO_InitTypeDef GPIO_InitStruct;
  if(htim_encoder->Instance==TIM2)
  {
    /* Peripheral clock enable */
    __TIM2_CLK_ENABLE();

    /**TIM2 GPIO Configuration
    PA0     ------> TIM2_CH1
    PA1     ------> TIM2_CH2
    */
    GPIO_InitStruct.Pin = GPIO_PIN_0|GPIO_PIN_1;
    GPIO_InitStruct.Mode = GPIO_MODE_AF_PP;
    GPIO_InitStruct.Pull = GPIO_NOPULL;
    GPIO_InitStruct.Speed = GPIO_SPEED_LOW;
    GPIO_InitStruct.Alternate = GPIO_AF1_TIM2;
    HAL_GPIO_Init(GPIOA, &GPIO_InitStruct);

  }
}

void HAL_TIM_Base_MspInit(TIM_HandleTypeDef* htim_base)
{

  if(htim_base->Instance==TIM6)
  {
    /* Peripheral clock enable */
    __TIM6_CLK_ENABLE();

    /* Peripheral interrupt init*/
    /* Sets the priority grouping field */
    HAL_NVIC_SetPriorityGrouping(NVIC_PRIORITYGROUP_3);
    HAL_NVIC_SetPriority(TIM6_DAC_IRQn, 5, 0);
    HAL_NVIC_EnableIRQ(TIM6_DAC_IRQn);
  }
}

void HAL_TIM_IC_MspInit(TIM_HandleTypeDef* htim_ic)
{

  GPIO_InitTypeDef GPIO_InitStruct;
  if(htim_ic->Instance==TIM15)
  {
    /* Peripheral clock enable */
    __TIM15_CLK_ENABLE();

    /**TIM15 GPIO Configuration
    PA3     ------> TIM15_CH2
    */
    GPIO_InitStruct.Pin = GPIO_PIN_3;
    GPIO_InitStruct.Mode = GPIO_MODE_AF_PP;
    GPIO_InitStruct.Pull = GPIO_NOPULL;
    GPIO_InitStruct.Speed = GPIO_SPEED_LOW;
    GPIO_InitStruct.Alternate = GPIO_AF9_TIM15;
    HAL_GPIO_Init(GPIOA, &GPIO_InitStruct);

    /* Peripheral interrupt init*/
    /* Sets the priority grouping field */
    HAL_NVIC_SetPriorityGrouping(NVIC_PRIORITYGROUP_3);
    HAL_NVIC_SetPriority(TIM1_BRK_TIM15_IRQn, 1, 0);
    HAL_NVIC_EnableIRQ(TIM1_BRK_TIM15_IRQn);
  }
}
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

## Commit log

2014-09-15 Create from private commit 1e99ea710
    [fwrtss-B_Cu.gbl, fwrtss-B_Mask.gbs, fwrtss-B_Paste.gbp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]
2014-09-16 SCH R07.1
    [fwrtss.sch]

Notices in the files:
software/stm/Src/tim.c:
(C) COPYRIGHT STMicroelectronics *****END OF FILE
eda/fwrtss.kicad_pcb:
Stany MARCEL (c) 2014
